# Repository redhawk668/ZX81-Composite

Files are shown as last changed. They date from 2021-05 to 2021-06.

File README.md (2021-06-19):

# ZX81 Composite Video with Backporch
This PCB provides composite video for the ZX81, it replaces the internal PCB from the modulator. For ZX81's with earlier type ULA's it generates a back porch signal.

It will work with the later 2C210 ULA. However, this ULA does provide a backporch signal, so the 555 timer chip is not needed and can be removed. It is based on instructions and schematics found on zx.zigg.net.

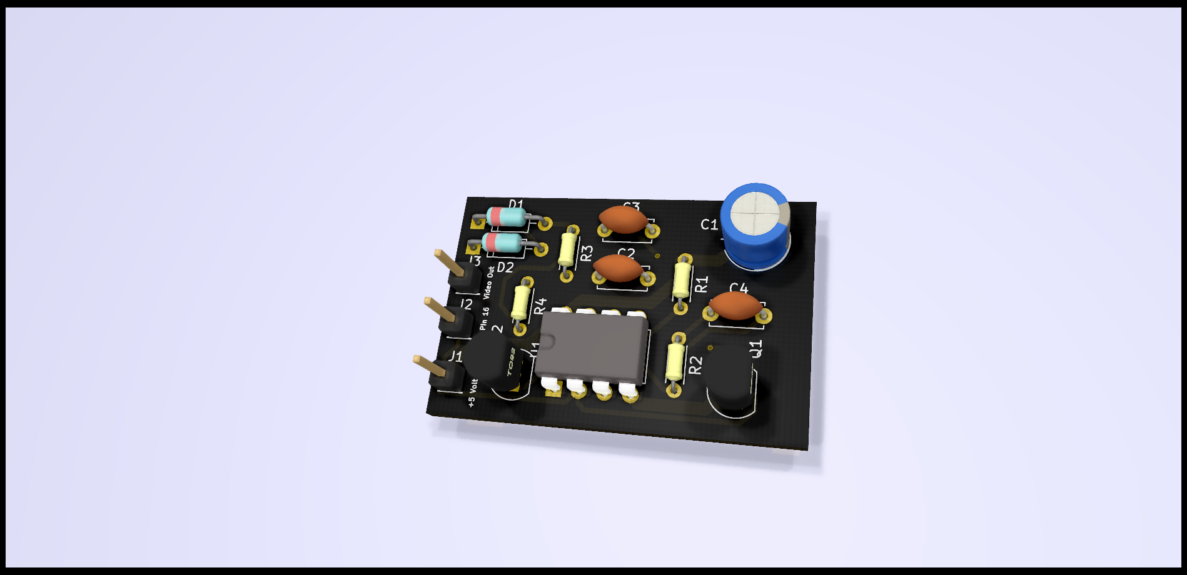
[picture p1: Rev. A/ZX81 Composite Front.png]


# Billing of Materials:

|Qty |Value  |Component |Package |PCB |
|----|---|---|---|---|
| 2x | 10K | Metal Film Resistors | Axial DIN204 | R1, R2  |  
| 1x | 68R | Metal Film Resistor | Axial DIN204 | R3 |
| 1x | 56R | Metal Film Resistor | Axial DIN204 | R4 |
| 1x | 10nF  | Ceramic Capacitor | Disc 5mm | C2 |
| 1x | 820pF | Ceramic Capacitor | Disc 5mm | C3 |
| 1x | 82pF  | Ceramic Capacitor | Disc 5mm | C4 |
| 1x | 22uF  | Electrolytic Capacitor | Radial 6.3mm | C1 |
| 2x | 1N4148| Diodes | DO-35 | D1, D2  |
| 2x | BC337 | Transistors | TO-92 | Q1, Q2  |
| U1 | NE555 | Timer IC | DIP-8 | U1 |
--------------------------------------------------------------------

# Usage:
Desolder the modulator case, remove the PCB and solder the new PCB in. Solder wires to the +5 volt input, video input and video output. Re-assemble the modulator case and solder it back on the ZX81 board. Connect video output with the RCA, connect +5 volt and video in with the correspending pads on the ZX81 board.

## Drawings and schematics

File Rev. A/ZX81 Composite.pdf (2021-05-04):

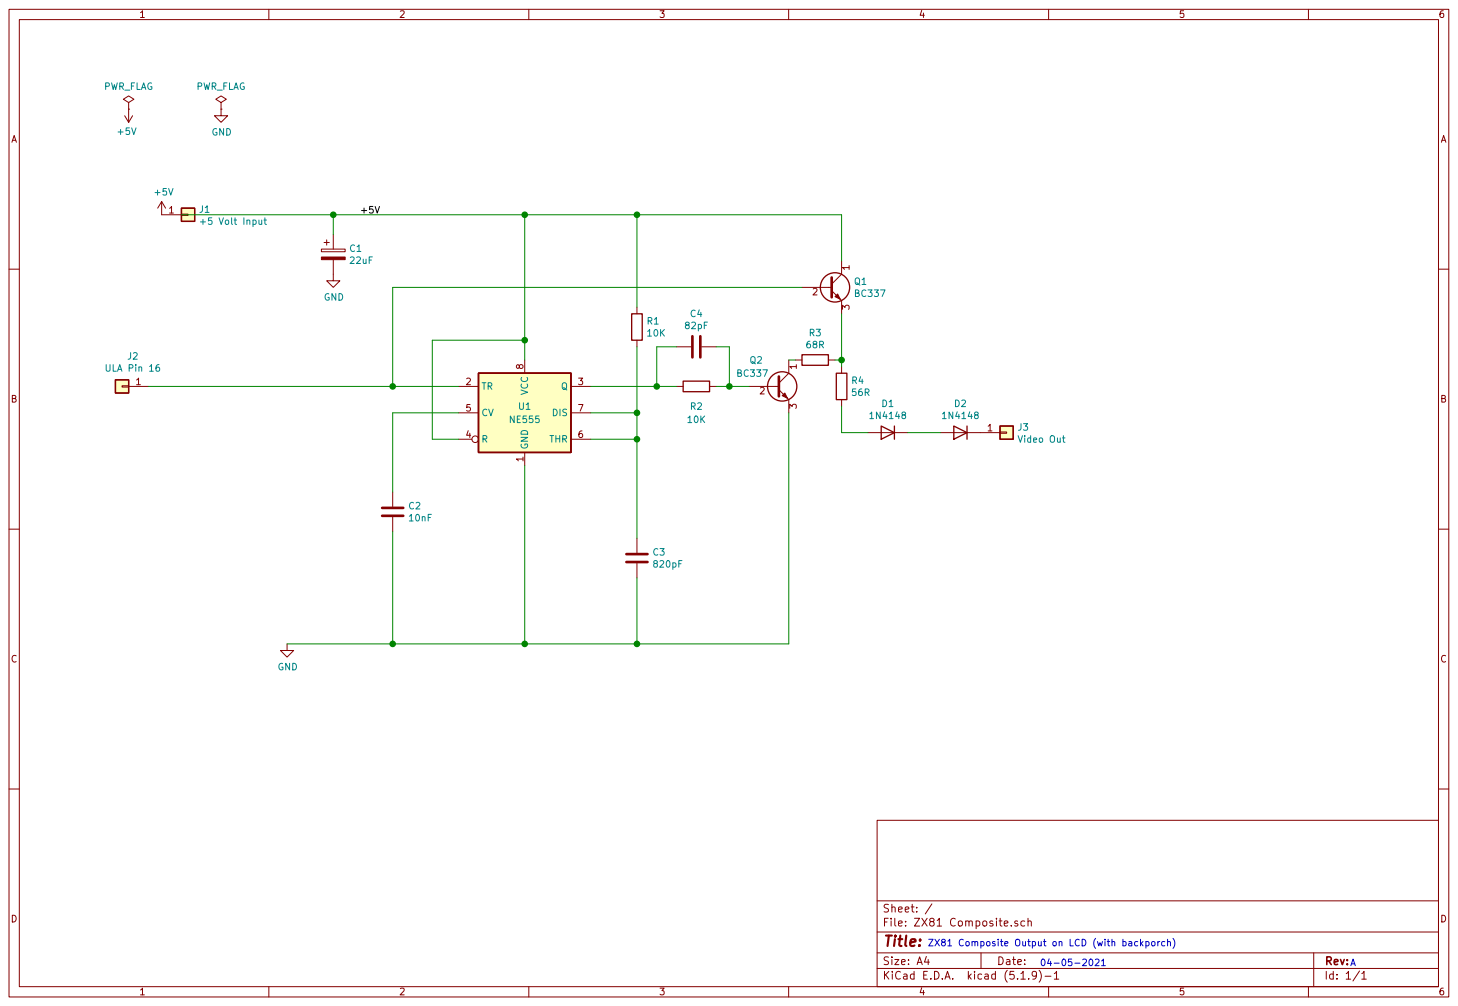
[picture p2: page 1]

File: ZX81 Composite.sch Sheet: /
Id: 1/1 Title:

ZX81 Composite Output on LCD (with backporch)

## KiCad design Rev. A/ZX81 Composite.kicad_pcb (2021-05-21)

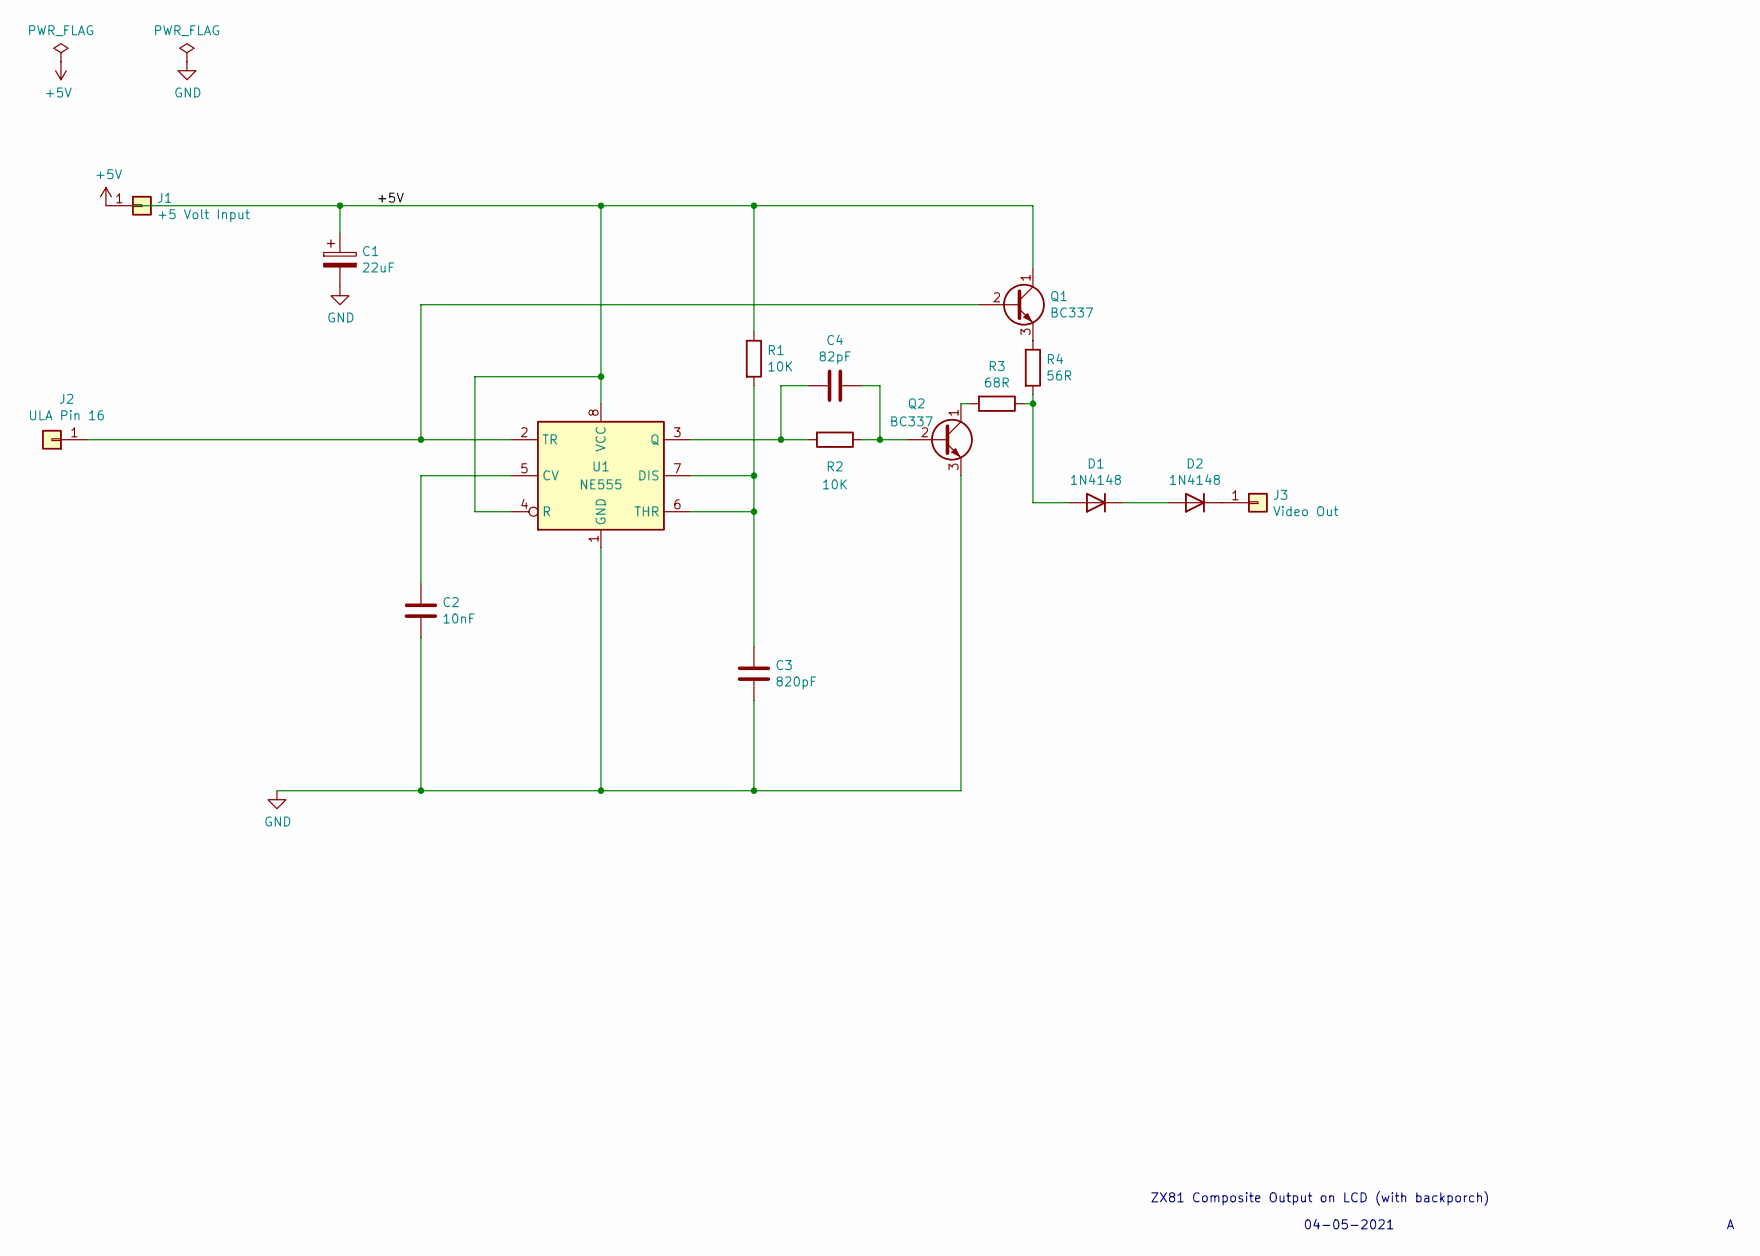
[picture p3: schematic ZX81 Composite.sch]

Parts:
C1: 22uF; CP_Radial_D6.3mm_P2.50mm
C2: 10nF; C_Disc_D5.0mm_W2.5mm_P5.00mm
C3: 820pF; C_Disc_D5.0mm_W2.5mm_P5.00mm
C4: 82pF; C_Disc_D5.0mm_W2.5mm_P5.00mm
D1, D2: 1N4148; D_DO-35_SOD27_P7.62mm_Horizontal
J1: +5 Volt Input; Pin_Header_Straight_1x01_Pitch2.54mm
J2: ULA Pin 16; Pin_Header_Straight_1x01_Pitch2.54mm
J3: Video Out; Pin_Header_Straight_1x01_Pitch2.54mm
Q1, Q2: BC337; TO-92_Inline_Narrow_Oval
R1, R2: 10K; R_Axial_DIN0204_L3.6mm_D1.6mm_P5.08mm_Horizontal
R3: 68R; R_Axial_DIN0204_L3.6mm_D1.6mm_P5.08mm_Horizontal
R4: 56R; R_Axial_DIN0204_L3.6mm_D1.6mm_P5.08mm_Horizontal
U1: NE555; DIP-8_W7.62mm

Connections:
+5V: C1.1, J1.1, Q1.1 (C), R1.1, U1.4 (R), U1.8 (VCC)
GND: C1.2, C2.2, C3.2, Q2.3 (E), U1.1 (GND)
unnamed: C2.1, U1.5 (CV)
unnamed: C3.1, R1.2, U1.6 (THR), U1.7 (DIS)
unnamed: C4.1, Q2.2 (B), R2.1
unnamed: C4.2, R2.2, U1.3 (Q)
unnamed: D1.1 (K), D2.2 (A)
unnamed: D1.2 (A), R3.1, R4.2
unnamed: D2.1 (K), J3.1
unnamed: J2.1, Q1.2 (B), U1.2 (TR)
unnamed: Q1.3 (E), R4.1
unnamed: Q2.1 (C), R3.2

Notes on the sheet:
ZX81 Composite Output on LCD (with backporch)
04-05-2021

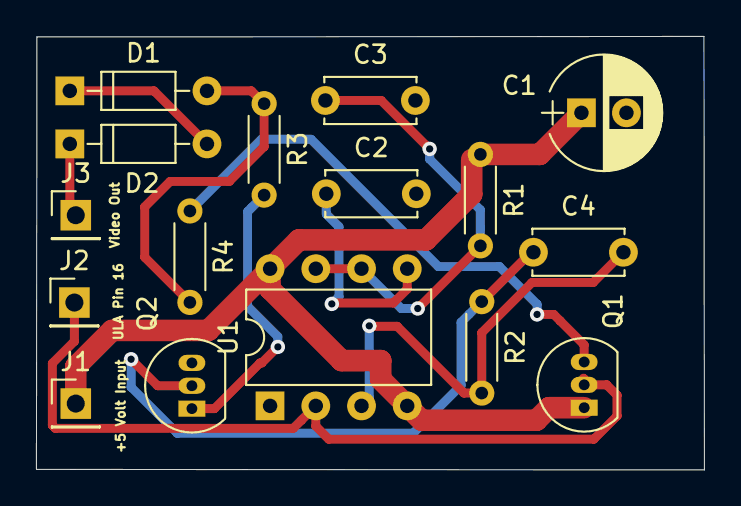
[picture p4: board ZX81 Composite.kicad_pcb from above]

Board: 2 copper layers, 37.1 x 24.1 mm, 16 parts (0 on the bottom side), 12 nets.

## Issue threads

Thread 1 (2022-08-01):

Sharing a build and install

kdorff, 2022-08-01:
You can close this. I just wanted to share.

I ordered the PCB from your repo and installed it in my TS1000 (US version of ZX81).  See https://imgur.com/gallery/2F53GVl

My thoughts, but no need to change anything.
* The position of the input/output pins nearly conflicts with the RCA jack (in the only orientation I could install the PCB). But it did work. Yay!
* I had trouble soldering the PCB to the can - getting the can to take solder. I realized LATER I needed to sand the can. I just soldered a ground wire to the bottom and brought that up (and then later sanded and soldered it to the insider of the can). My 22AWG solid core wire was a very tight fit to bring a ground from the bottom :)
* The video looks great!

My only suggestion MIGHT be to add a pin for ground, in case you don't want to solder it at the bottom to the can. But I should have realized to sand the inside of the can and it would have probably soldered just fine. And I should have used a fatter tip, maybe.

0ddjob, 2022-08-14:
Yep, I came across the same issue with the RCA jack last night in my TS1000!  In the ZX81 the RCA jack is at the other end of the modulator can so I believe this is what it was designed for.

For soldering the ground to the can you could also try using some flux paste - this helps the solder adhere to the can.

Unfortunately I need to troubleshoot mine a bit more - the modulator can is somehow ending up at around 4.5V rather than ground ... but it's good to hear some someone that it does actually work!

[2022-08-15 09 29 07](https://user-images.githubusercontent.com/24483449/184558871-c1fe4325-b6f6-4235-a365-d1ef73a8b0c0.jpg)

Brett.

kdorff, 2022-08-14:
I'm betting you bridged the legs on one of the transistors.

0ddjob, 2022-08-15:
Ah huh, thanks, will have a proper look ... the legs are quite close together, aren't they! ;)  Your suggestion about an additional ground pin is good - the original strip board design has this, and this is also how I wire up the simple emitter-follower buffer I've been using before trying this out.  Of course, space is already at a premium on this board.
Brett.

0ddjob, 2022-08-16:
Still not working.  Made up a 2nd board - no go.  I've found that there's two similar designs - the main difference being transistor - BC337 in this one and 2N2222 in the other.

kdorff, 2022-08-16:
I've built this circuit and used it in two TS1000's. One that had a back porch (I omitted the 555) and one didn't. It worked great for both.

Check your components and solder joints is all I can think. I first ran it outside of the can, running a ground wire to a bottom pad for testing. Make sure to take the video signal from pin 16 directly or use UK2 next to the RF can (but I wouldn't use USA3).

If you have a microscope, use that to check the solder joints on the transistor. This was initially my problem.

There was, from the original RF circuitry, a coil (?) and a capacitor soldered to the RCA Jack. I removed those before doing any testing.

I found the schematic [in this pdf](https://k1.spdns.de/Vintage/Sinclair/80/Sinclair%20ZX81/Service%20and%20Assembly%20Manual/ZX81%20Service%20and%20Assembly%20Manual%20(scans).pdf) to be helpful.
